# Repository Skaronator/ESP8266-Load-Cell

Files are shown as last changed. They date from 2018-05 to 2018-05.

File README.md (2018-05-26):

# ESP8266 Load Cell
A MQTT client to read out the result of HX711 and send it to a MQTT Broker.

#### This is a (somewhat) fork of [newAM/LoadCellOccupany](https://github.com/newAM/LoadCellOccupany/). Be sure to check his repository out!

## Hardware

This is the exact Hardware I'm using. It cost around 5-10€ on AliExpress.
- ESP8266 - [WeMos D1 mini Pro](https://wiki.wemos.cc/products:d1:d1_mini_pro)
- ADC - HX711
- Load Cell - Search for "50kg load cell hx711" on AliExpress. It'll have a HX711 included.
- 3D printed case for the load cell.

## Software

You need some libarys to compile this Arduino Sketch.
- [esp8266/Arduino](https://github.com/esp8266/Arduino#installing-with-boards-manager) - Install via Arduino IDE
- [async-mqtt-client](https://github.com/marvinroger/async-mqtt-client) - [ZIP Download](https://codeload.github.com/marvinroger/async-mqtt-client/zip/master)
- [ESPAsyncTCP](https://github.com/me-no-dev/ESPAsyncTCP) - [ZIP Download](https://codeload.github.com/me-no-dev/ESPAsyncTCP/zip/master)
- [HX711](https://github.com/bogde/HX711) - [ZIP Download](https://codeload.github.com/bogde/HX711/zip/master)

Please [open a Issue](https://github.com/Skaronator/ESP8266-Load-Cell/issues) if you have trouble to compile.

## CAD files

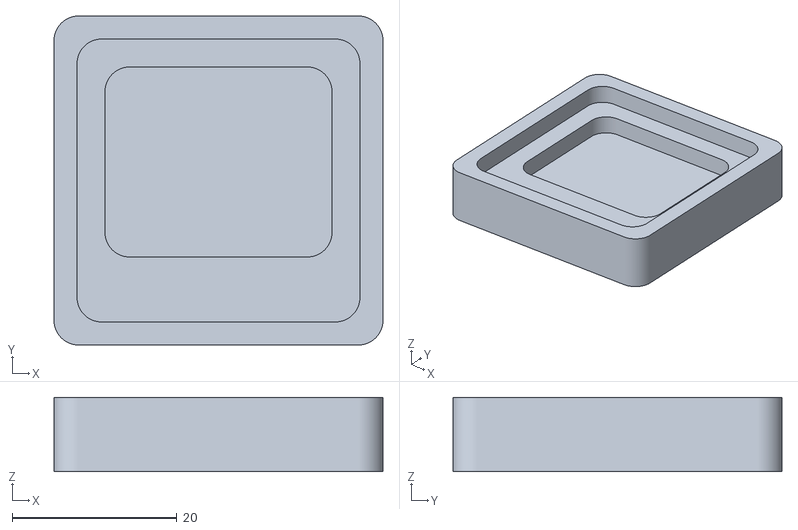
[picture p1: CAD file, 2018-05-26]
3D-Print/LoadCell_Holder_modified.stl
40.0 x 40.0 x 9.00

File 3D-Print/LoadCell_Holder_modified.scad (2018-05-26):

// render settings
fn  = 100;     // sides to render on cylinder
cut = 0.001;   // exact cutouts do not render

// Makes a cube shape with rounded corners in the z-direction
// dim[x,y,z] - vector containing outer dimensions of the cube
// rad        - radius of the rounded corners 
module RoundCorners(dim, rad) {
    // create adjusted dimensions for corners
    adjDim = [dim[0] - rad * 2, dim[1] - rad * 2, dim[2]];

    hull() {
        // place cylinders at each corner
        for (x = [1, -1])
            for (y = [1, -1])
                translate([x * adjDim[0] / 2,   y * adjDim[1] / 2, 0])
                    cylinder(h = adjDim[2], r = rad, center = true, $fn = fn);

        // place main body
        cube(adjDim, center = true);
    }
}

// clearances
clear = 0.2;    // clearance from load cell to wall

// load cell measured dimensions
loadCellX = 34;  // length and width of load cell
loadBaseX = 3;   // width of load cell base
loadBaseB = 7.5; // width of load cell base at the strain gauge

// wall thickness
wall = 3;        // wall thickness

roundR = 3;      // radius of rounded corners

// derived dimensions
base    = [loadCellX + wall * 2, loadCellX + wall * 2, wall];
baseCut = [loadCellX - (loadBaseX + clear) * 2, 
           loadCellX - loadBaseX - loadBaseB - clear * 2, 
           wall + cut];
wallCut = [loadCellX + clear * 2, 
           loadCellX + clear * 2, 
           base[2] + cut];
           
flatBase = [loadCellX + wall * 2, loadCellX + wall * 2, wall];

union() {
    // base with cutout for load cell to deflect
    difference() {
        RoundCorners(base, roundR);
        translate([0, (loadBaseB - loadBaseX) / 2, 0])
            RoundCorners(baseCut, roundR);
    }
    
    difference() {
        translate([0, 0, wall * -1])
            RoundCorners(flatBase, roundR);
    }

    // walls to hold load cell
    difference() {
        translate([0, 0, wall])
            RoundCorners(base, roundR);
        translate([0, 0, wall])
            RoundCorners(wallCut, roundR);
    }
}

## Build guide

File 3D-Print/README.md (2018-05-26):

This is a modified version of [**@newAM**](https://github.com/newAM) load cell holder. It has a solid base (3mm) to mount it better with double sided tape.

Original Version: https://github.com/newAM/LoadCellOccupany/tree/master/LoadCell_Holder

Software used: [OpenSCAD](http://www.openscad.org/)

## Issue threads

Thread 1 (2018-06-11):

Number of load cells

danpowell88, 2018-06-11:
Are you using a single load cell or multiple?

Skaronator, 2018-06-24:
Sorry for the late response! I didn't got a E-Mail or missed it...

I'm using 4 loadcells on a single HX711. Here is the wiring diagram:

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

Closed 2018-06-24.

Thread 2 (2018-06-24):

Reset oldResult variable on MQTT Disconnect

Skaronator, 2018-06-24:
When the MQTT server goes offline and comes back it should re-send the current value.

Skaronator, 2018-09-10:
It should also send the value every x min even if it didn't changed to show that the device is still alive.

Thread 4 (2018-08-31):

Connection Photos

bachoo786, 2018-08-31:
Hello

Can you please show the connection of the load cells to the load cell sensor as well as to the Wemos?

Thank you.

Skaronator, 2018-08-31:
Hey,

did you saw the image in #1? The HX711 is via Pin D3 and D4:

https://github.com/Skaronator/ESP8266-Load-Cell/blob/ea1dd6d372639417d1c046c552d9748194dad7fe/code/config.h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

Here is the best image I could get without unpluging it :p

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

Skaronator, 2018-09-10:
If you have more questions, feel free to comment below.

bachoo786, 2018-10-01:
hey @Skaronator didnt realize that you had replied.

I tried to upload the code to my esp8266 board but it gives an error saying pin D3 and D4 have not been defined in config.h ? I thought they were already pre-defined?

Thanks.

bachoo786, 2018-11-18:
Hi thanks for the reply
I mounted the load sensors on my bed 4 of them but the weight is not distributed on the mattress as the sensor does not detect the weight until pressured is applied on it i.e. on the side of the bed.

Do you have any idea what could be wrong?

Closed 2018-09-10.

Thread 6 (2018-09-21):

Getting boot loop errors

hammondses, 2018-09-21:
Hi there,

I'm attempting to get my Wemos D1 Mini Pro working with your bed sensor scripts, however after flashing both files I'm getting reboot errors.

I modified config.h to suit my config, should I try it with yours?

I'm really new to the whole ESP8266 thing so please be gentle :)

I have wired it all correctly (I think) SCL -> SCK, SDA -> DT, 5v -> VCC & GND -> GND from ESP to HX711. I followed the diagram provided for the weight sensors to be wired to eachother and back to the HX711.

In the Serial Monitor I get total garbage at 9600 baud, but at 115200 I get this:

```
ets Jan  8 2013,rst cause:2, boot mode:(3,7)

load 0x4010f000, len 1384, room 16
tail 8
chksum 0x2d
csum 0x2d
vbb28d4a3
~ld
```

Any help would be greatly appreciated!

hammondses, 2018-09-21:
Update: Fixed my bootloop issues, issue was I needed to change the pins in the config, so now it boots but my monitor is full of absolute garbage no matter the baud I use :(

Skaronator, 2018-09-21:
I'm actually not sure why the output is sometimes just garbage.

Did you install the Wemos Board Stuff? https://www.instructables.com/id/Programming-the-WeMos-Using-Arduino-SoftwareIDE/

hammondses, 2018-09-21:
I think it's because it's a knock off from AliExpress, the WiFi test module seems to do nothing which doesn't look like a good sign from what I've been reading

Skaronator, 2018-09-21:
Could you make a picture of it and maybe link the AliExpress product?

hammondses, 2018-09-21:
https://s.click.aliexpress.com/e/b8QSpZQY

I'm not at home right now but I'll take a picture of it tomorrow when I'm home

Skaronator, 2018-09-21:
Weird thats a LOLIN and not a Wemos. Mine looks completly different but just checked the Wemos page and it looks like they have a new version? https://wiki.wemos.cc/products:d1:d1_mini_pro

Mine looks like this: (Notice the ceramic antenna)

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

hammondses, 2018-09-21:
I think the easiest thing for me to do is probably buy the same one you have, this is it? - https://www.trademe.co.nz/1773192104

Skaronator, 2018-09-21:
Yes I think so but $14 is too expensive for that. This is what I've ordered earlier this year: https://www.aliexpress.com/item/WEMOS-D1-Mini-Pro-V1-0-16M-Bytes-External-Antenna-Connector-NodeMCU-ESP8266-ESP8266F-CP2104-WIFI/32861321679.html

(Just noticed that 1.0 not 1.1 but shouldn't matter)

Skaronator, 2018-09-21:
Bascially it should be possible to run this on the v2 version but I don't have the hardware to validate this. Maybe I'll order some but it'll take almost a month until they are here.

hammondses, 2018-09-21:
Ah, it's in NZD. The AliExpress link you gave is $11.77 so not too bad for it being local. I'll order one and let you know how I get on :)

Skaronator, 2018-09-21:
Oh it's local? Didn't know that. The AliExpress link is $5 for me.

hammondses, 2018-09-21:
Yeah, I did mean Inc shipping :)

I guess the issue too is that it's pretty difficult to find someone to test it who happens to have load sensors and the v2 hardware

hammondses, 2018-09-23:
I'm now getting this error after fixing the pinouts in the code:

`16:52:26.210 ->  ets Jan  8 2013,rst cause:2, boot mode:(3,6)
16:52:26.210 ->
16:52:26.210 -> load 0x4010f000, len 1384, room 16
16:52:26.210 -> tail 8
16:52:26.210 -> chksum 0x2d
16:52:26.210 -> csum 0x2d
16:52:26.255 -> vbb28d4a3
16:52:26.255 -> ~ld
`

hammondses, 2018-09-23:
I decided to test the esp with a whole range of test sketches and it seems like all of the onboard functions are working and the HX711 calibration sketch gives me readouts of the load sensors.

After a bit of googling it seems it's quite a common error I'm getting when trying to use the hx711 and an esp8266, apparently putting in a yeild somewhere can fix it?

See here - https://github.com/bogde/HX711/issues/67

bachoo786, 2018-10-04:
@hammondses did you upload the code before connecting hx711 and the load cells?  Because I am uploading the code before attaching anything onto my esp8266 and I get errors as described in your first post.

Please help.

hammondses, 2018-10-04:
I uploaded the code after connecting everything, which hardware revision are you using?

bachoo786, 2018-10-04:
Sorry what do you mean by hard revision ?

hammondses, 2018-10-04:
Oh sorry I meant which esp do you have? I had the new version of the d1 mini pro which didn't seem to like the code so I'm waiting for the same revision to arrive which the creator has :)

bachoo786, 2018-10-04:
I have the old version of d1 mini  and have the nodemcu none of them work I get the same error as described earlier.

hammondses, 2018-10-07:
Hmm how odd, @Skaronator any suggestions?

Skaronator, 2018-10-07:
Sorry, can't really help you since I'm relatively new to the whole Arduino stuff.

hammondses, 2018-10-14:
@bachoo786 Which error are you seeing? If its the absolute garbage in the output monitor I fixed it on mine, I had to run a script to set the default baud rate of the ESP8266 to 9600 and did an AT+IPR=9600 command, then uploaded the sketch (I can't remember if it was sketch only or sketch+wifi) and it seems to have fixed it.

I gave up trying to get my version 2 board working, but the one that you have and the OP has I got working after setting the default baud rate of the board lower.

Let me know how you get on!

hammondses, 2018-10-17:
@Skaronator what does your history graph for the sensor look like? For some reason i'm experiencing huge weight fluctuations randomly in the middle of the night or during the day for a few moments then back to normal. See attached picture

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

amotl, 2019-02-19:
Hi there, just wanted to let you know we are working on https://github.com/bogde/HX711/pull/123, which you might want to give a try. It is an attempt to remedy some of the issues of this library, especially when it came to ESP8266 and ESP32 support.

sagartec, 2019-10-19:
@hammondses did you solve the reset problem. I am also facing the same issue now.

hammondses, 2019-10-19:
Yeah I ended up changing to the exact same board as the original poster was using, also noticed some boards don't like having the letter in the pinout, ie D3 D2 I changed to 3 and 2 which resolved my issues with other projects.

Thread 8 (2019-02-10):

Crash every now & then

riemers, 2019-02-10:
I have all running, i added a scale set option since when i restart i would not be in bed ;)

Problem is it sometimes just 'dies'. When that happens it restarts dumping errors on the screen before restarting. Somtimes it works for a long time and sometimes it just goes into the reboot phase.

Is there anything i can do to improve this/debug?

Other then that, the instructions where just fine. Only thing i didn't know was that you need the molds otherwise it doesn't bend correctly. (i was just pressing it for testing, gives weird values)

amotl, 2019-02-19:
Hi there, this might be a duplicate of #6 already. Just wanted to let you know we are working on https://github.com/bogde/HX711/pull/123, which you might want to give a try. It is an attempt to remedy some of the issues of the Arduino HX711 library, especially when it came to ESP8266 and ESP32 support.

riemers, 2019-02-19:
i have a wemos mini i believe, but if this would reduce the 'crashes' that would certainly help. Time is shorthanded but if i do i'll test it out.

amotl, 2019-02-20:
@bogde [confirmed](https://github.com/bogde/HX711/pull/123#issuecomment-465038328) that the revamped code works out of the box with a WeMos D1 mini (ESP8266) already. There are chances it might be actually behave better as the library gained minor but important improvements through suggestions from the community.

So, if you like give it a try. However I can't promise the overall system stability will actually be better using the improved HX711 code as there might be other things involved. Good luck!

riemers, 2019-03-04:
@amotl i've tested it out, it does seem a lot more stable now. Only weird thing is that i get random values sometimes.

14:29:34.216 -> Pushing new result:    0
14:51:40.903 -> Pushing new result:  -43
14:51:41.417 -> Pushing new result:    0
15:01:47.977 -> Pushing new result:   -1
15:01:48.566 -> Pushing new result:    0
15:06:54.438 -> Pushing new result:   -1
15:06:54.954 -> Pushing new result:    0
23:13:29.948 -> Pushing new result:   -1
23:13:30.427 -> Pushing new result:   22
23:13:30.939 -> Pushing new result:    0
20:25:56.308 -> Pushing new result:   20
20:25:56.792 -> Pushing new result:    0

When it happens its pretty quick to drop back to 0, have no load on it. But its a bit weird to be so spikey (this is in kg)

amotl, 2019-03-04:
Dear @riemers,

> i've tested it out, it does seem a lot more stable now

Thanks for testing, sounds good.

> Only weird thing is that i get random values sometimes.

The readings as displayed are obviously weird. While we did our best to incorporate all the relevant changes into https://github.com/bogde/HX711/pull/123 where some of them also account for reading the data from the hardware using faster chips, there might still be issues with the ESP8266 we dearly would like to find out about.

### Research
When searching for other issues about random readings over at https://github.com/bogde/HX711, I've found two issues which might be relevant:

- https://github.com/bogde/HX711/issues/28#issuecomment-191370341
  > I actually stopped using the HX711 because at higher read rates (40Hz) it would seem to randomly give bad data. I have a suspicion this is actually due to the internal buffer getting updated with a new conversion while you're still clocking out the previous conversion data. I also needed 100Hz conversion, so I moved to ADS1232 with an external clock.
- https://github.com/bogde/HX711/issues/47

### Thoughts
So, while the current code should account for properly slowing down the reading from the hardware appropriately (https://github.com/bogde/HX711/blob/0.7.2/src/HX711.cpp#L36-L62), let's check this twice: Can we humbly ask you to run your sketch either with reduced clock speed or by adjusting the value used within the calls to `delayMicroseconds(1);` there?

### Advise
We would also recommend to open a corresponding issue over at https://github.com/bogde/HX711/issues/new to get more eyeballs on that.

Thanks already for your efforts.

With kind regards,
Andreas.

riemers, 2019-03-05:
I'll see what i can do, i still have the "test" setup on my desk. Just need some time :)

riemers, 2019-03-05:
Also noticed some crashes again:

```
14:36:50.017 -> Pushing new result:    0
14:36:57.611 -> [WiFi] Disconnected from Wi-Fi!
14:36:58.568 -> Pushing new result:    3
14:36:59.050 -> Pushing new result:    0
14:36:59.627 -> [WiFi] Connecting to n176...
14:36:59.627 ->
14:36:59.627 -> Exception (9):
14:36:59.662 -> epc1=0x40105068 epc2=0x00000000 epc3=0x00000000 excvaddr=0x00000003 depc=0x00000000
14:36:59.766 ->
14:36:59.766 -> >>>stack>>>
14:36:59.766 ->
14:36:59.766 -> ctx: sys
14:36:59.766 -> sp: 3fffed10 end: 3fffffb0 offset: 01a0
14:36:59.835 -> 3fffeeb0:  40105294 21f39217 3ffee968 00000000
```

```
15:30:44.045 -> Pushing new result:    0
16:31:21.412 -> [WiFi] Disconnected from Wi-Fi!
16:31:23.395 -> [WiFi] Connecting to n176...
16:31:23.395 ->
16:31:23.395 -> Exception (9):
16:31:23.429 -> epc1=0x40105068 epc2=0x00000000 epc3=0x00000000 excvaddr=0x00000003 depc=0x00000000
16:31:23.531 ->
16:31:23.531 -> >>>stack>>>
16:31:23.531 ->
16:31:23.531 -> ctx: sys
16:31:23.531 -> sp: 3fffed10 end: 3fffffb0 offset: 01a0
16:31:23.600 -> 3fffeeb0:  40105294 1f4dd11d 3ffee968 00000000
```

Looking at this, the wifi is disconnecting for some reason, but when it reconnects it crashes.

Later on:

```
16:31:32.688 -> [WiFi] Connecting to n176...
16:31:33.204 -> Pushing new result:    0
16:31:33.887 -> [WiFi] Disconnected from Wi-Fi!
16:31:34.644 -> [WiFi] Connected, IP address: 192.168.1.23
16:31:34.678 -> [MQTT] Connecting to MQTT...
16:31:49.273 -> Pushing new result:   -0
16:31:51.290 -> Pushing new result:    0
```

Seems that if it wants to push a new value while it was disconnect or just about might make it crash. (assuming not related to hx711(

Your saying to delay, but do you mean a delay in my void loop? Since it already has a 100ms delay.

riemers, 2019-03-07:
Is it normal that it crashes totally too? I changed the sample rates:

#define SAMPLE_PERIOD 100    // sample period in ms
#define NUM_SAMPLES   10      // number of samples - max 255 - published mqtt update every NUM_SAMPLES * SAMPLE_PERIOD = ms

```
22:43:11.645 -> [WiFi] Disconnected from Wi-Fi!
22:43:13.130 -> Pushing new result:  0.0
22:43:14.520 -> [WiFi] Disconnected from Wi-Fi!
22:43:18.154 -> Pushing new result: -0.0
22:43:19.158 -> Pushing new result:  0.0
22:43:19.503 -> [WiFi] Connecting to n176...
22:43:26.987 -> H⸮)2
```

Also notice no longer a blue light anymore and no reaction anymore. But with 100/10 it was not better. With 200/5 it was only a few kg minus sometimes. I'll try 300/3 now :)

amotl, 2019-03-07:
Dear @riemers,

sorry that it doesn't work for you. Would there be any chance you could try this with a more recent firmware version? I believe the ESP8266 had some issue with older firmwares which have been similar to what you are reporting. Also, I haven't investigated [LoadCell.ino](https://github.com/Skaronator/ESP8266-Load-Cell/blob/master/code/LoadCell.ino) in detail yet, where things might go wrong too.

With kind regards,
Andreas.

riemers, 2019-03-09:
@amotl i'am pretty new to the boards, i only know i can flash a sketch from arduino ide or use the espeasy which also seems to support hx711 in the test environment. Have a wemos d1 mini and have yet to find a newer 'firmware'. I tried espeasy too, but this is just an easy gui thing for people, not really my thing when it comes to keeping it clean and simple ;) any pointers/hints and i'll check it out.

amotl, 2019-03-09:
Thanks for the insight, @riemers. Then, I would recommend to start small again by testing with one of the canonical examples provided with the HX711 library.

Why not start over with the most basic one ([HX711_basic_example.ino](https://github.com/bogde/HX711/blob/master/examples/HX711_basic_example/HX711_basic_example.ino)) again, in order to check that this (hopefully!) **does not** crash your machine.

riemers, 2019-03-09:
Ah yes, start from basic is a good idea too. I have it hooked up to the com anyways. I can just let it sit and see if its stable and then expand if it runs good for a few days etc etc. I'll keep you posted (then you know if it has any relationship with hx711)

riemers, 2019-03-09:
20:50:15.387 -> HX711 reading: -150552
20:50:16.380 -> HX711 not found.
20:50:17.403 -> HX711 reading: -150494

That normal now and then?

amotl, 2019-03-09:
Interesting, thanks for letting us know. I really can't tell anything about effects like that. Obviously all of us expect stable readings and I didn't hear about corresponding reports either.

As far as I learned, many things can contribute to things going wrong when reading the HX711.

"not found" would actually be a bit misleading here. It should really be called "not available" or "unable to read" or such.

Is the rate of valid readings acceptable for you? I mean, **if** they're actually valid then.

riemers, 2019-03-09:
Well you have to tare it, but other then that the value is now around -151000 and its doesn't go higher/lower then +- 250 side ways. (From what i gather, thats pretty descent)

The **not found** has happened now 8 times since 20:37 till now. I would call that "acceptable" since we read it out so many times anyways.

amotl, 2019-03-09:
Hi @riemers,

when taking a reading each second, eight faulty readings during more than two hours also seems acceptable for this ensemble of hardware and software, right? We are not conducting measurements for ATLAS here in the end.

With kind regards,
Andreas.

riemers, 2019-03-09:
Indeed, i'll leave it spitting out values for a couple of days. I normally had about 1 or 2 days tops before it went for a coffee break.

riemers, 2019-03-14:
Did some more testing, found out that the example was doing just fine. Only difference was that it sits at 115200. Had mine at 9600. Weirdly enough my original sketch is running now fine for 3 days without a crash when i changed it to 115200. Might be luck? Dunno but i'll keep it running for the weekend too and if it does then that was the culprit (although i believe it should not matter at all right?)

riemers, 2019-03-21:
@amotl well its been running now for more then a week and has not crashed anymore. Is it really that silly that the speed @ 115200 makes it not crash? Either way, i'am happy its running ok now :)

bogde, 2019-03-22:
@riemers it does make some sense though. since serial communication is now faster, it's less likely for that to interfere with anything else. glad it works for you now. cheers!

amotl, 2019-03-22:
Thanks for letting us know, have a good weekend and also cheers!

riemers, 2019-03-22:
We can close this, but a note somewhere might be good althought the example was with a higher rate. That was the only thing different when testing.

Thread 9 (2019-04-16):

Some step by step help for a noob

jjanderson, 2019-04-16:
Hello,

I am sorry to ask, but do you have some step by step instructions? I have never done a project like this, but I am desperate to try. I have just ordered all the components you listed.

Sorry for the stupid question, but will I also need an adruino board in addition to the hardware you listed?

Thanks for any help you are able to provide. My goal is to add this bed occupancy sensor to our toddlers bed and then plug into Home Assistant... possibly using the ESPHome component...

Thanks again for any help you can give me

aaamoeder, 2019-05-16:
I'd love this too.. no idea how to wire this up .. some pictures, and steps would be great !

jjanderson, 2019-05-16:
I have most of the kit now, just wanted to add this piece to the recommended hardware: [https://www.sparkfun.com/products/13878](url)

As the load cells have a rather short wire, I will need to extend the wires as well which will add further complication. (I want to use this on a baby cot)

Anyway, I would be happy to write this up as soon as I get it right…

Ulrar, 2019-10-15:
Hey,

Did you manage to get this working in the end ?
I would also be interested in details on how this all fits together.

qHack, 2020-01-04:
Anyone make progress here? I’m a software engineer by trade, need some pointers in the hardware parts.

jjanderson, 2020-02-27:
I am useless with a soldering iron, but hopefully will have it all hooked up by the weekend....

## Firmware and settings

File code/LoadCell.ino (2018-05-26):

// Required Libarys:
// async-mqtt-client:  https://codeload.github.com/marvinroger/async-mqtt-client/zip/master
// ESPAsyncTCP:        https://codeload.github.com/me-no-dev/ESPAsyncTCP/zip/master
// HX711:              https://codeload.github.com/bogde/HX711/zip/master

#include <ESP8266WiFi.h>
#include <EEPROM.h>
#include <Ticker.h>
#include <AsyncMqttClient.h>
#include <HX711.h>
#include <ArduinoOTA.h>
#include "config.h"


HX711 scale(PIN_DOUT, PIN_CLK);

AsyncMqttClient mqttClient;
Ticker mqttReconnectTimer;

WiFiEventHandler wifiConnectHandler;
WiFiEventHandler wifiDisconnectHandler;
Ticker wifiReconnectTimer;

bool firstRun = true;
unsigned char samples;
int sum, average, offset;
char oldResult[10];

void eeWriteInt(int pos, int val) {
    byte* p = (byte*) &val;
    EEPROM.write(pos, *p);
    EEPROM.write(pos + 1, *(p + 1));
    EEPROM.write(pos + 2, *(p + 2));
    EEPROM.write(pos + 3, *(p + 3));
    EEPROM.commit();
}

int eeGetInt(int pos) {
  int val;
  byte* p = (byte*) &val;
  *p        = EEPROM.read(pos);
  *(p + 1)  = EEPROM.read(pos + 1);
  *(p + 2)  = EEPROM.read(pos + 2);
  *(p + 3)  = EEPROM.read(pos + 3);
  return val;
}


void connectToWifi() {
  Serial.printf("[WiFi] Connecting to %s...\n", WIFI_SSID);

  WiFi.hostname(WIFI_CLIENT_ID);
  WiFi.mode(WIFI_STA);
  if (WIFI_STATIC_IP != 0) {
    WiFi.config(WIFI_CLIENT_IP, WIFI_GATEWAY_IP, WIFI_SUBNET_IP, WIFI_DNS_IP);
  }

  delay(100);

  WiFi.begin(WIFI_SSID, WIFI_PASSWORD);
}

void onWifiConnect(const WiFiEventStationModeGotIP& event) {
  Serial.print("[WiFi] Connected, IP address: ");
  Serial.println(WiFi.localIP());
  wifiReconnectTimer.detach();
  connectToMqtt();
}

void onWifiDisconnect(const WiFiEventStationModeDisconnected& event) {
  Serial.println("[WiFi] Disconnected from Wi-Fi!");
  mqttReconnectTimer.detach(); // ensure we don't reconnect to MQTT while reconnecting to Wi-Fi
  wifiReconnectTimer.once(WIFI_RECONNECT_TIME, connectToWifi);
}

void connectToMqtt() {
  Serial.println("[MQTT] Connecting to MQTT...");
  mqttClient.connect();
}

void onMqttConnect(bool sessionPresent) {
  Serial.println("[MQTT] Connected to MQTT!");

  mqttReconnectTimer.detach();

  Serial.print("Session present: ");
  Serial.println(sessionPresent);
  uint16_t packetIdSub = mqttClient.subscribe(MQTT_TOPIC_TARE, MQTT_TOPIC_TARE_QoS);
  Serial.print("Subscribing to ");
  Serial.println(MQTT_TOPIC_TARE);
}

void onMqttDisconnect(AsyncMqttClientDisconnectReason reason) {
  Serial.println("[MQTT] Disconnected from MQTT!");

  if (WiFi.isConnected()) {
    Serial.println("[MQTT] Trying to reconnect...");
    mqttReconnectTimer.once(MQTT_RECONNECT_TIME, connectToMqtt);
  }
}

void onMqttMessage(char* topic, char* payload, AsyncMqttClientMessageProperties properties, size_t len, size_t index, size_t total) {
  if (!strcmp(topic, MQTT_TOPIC_TARE)) {
    Serial.print("Zeroing: ");
    Serial.println(average / (float) 100);
    offset = average;
    if (SAVE_TARE != 0) {
      Serial.print("Saving to EEPROM...");
      eeWriteInt(EEPROM_ADDRESS, offset);
    }
  }
}

void setup() {
  Serial.begin(9600);
  EEPROM.begin(512);
  Serial.println("Startup!");

  wifiConnectHandler = WiFi.onStationModeGotIP(onWifiConnect);
  wifiDisconnectHandler = WiFi.onStationModeDisconnected(onWifiDisconnect);

  mqttClient.onConnect(onMqttConnect);
  mqttClient.onDisconnect(onMqttDisconnect);
  mqttClient.onMessage(onMqttMessage);
  mqttClient.setServer(MQTT_HOST, MQTT_PORT);

  if (MQTT_USER != "") {
    mqttClient.setCredentials(MQTT_USER, MQTT_PASS);
  }

  if (SAVE_TARE == 1) {
    offset = eeGetInt(EEPROM_ADDRESS);

    Serial.print("Loading offset from EEPROM: ");
    Serial.println(offset / (float) 100);
  }

  scale.set_scale(CALIBRATION);

  if (OTA_PATCH == 1) {
    ArduinoOTA.onStart([]() {
      String type;
      if (ArduinoOTA.getCommand() == U_FLASH) {
        type = "sketch";
      } else { // U_SPIFFS
        type = "filesystem";
      }

      // NOTE: if updating SPIFFS this would be the place to unmount SPIFFS using SPIFFS.end()
      Serial.println("Start updating " + type);
    });
    ArduinoOTA.onEnd([]() {
      Serial.println("\nEnd");
    });
    ArduinoOTA.onProgress([](unsigned int progress, unsigned int total) {
      Serial.printf("Progress: %u%%\r", (progress / (total / 100)));
    });
    ArduinoOTA.onError([](ota_error_t error) {
      Serial.printf("Error[%u]: ", error);
      if (error == OTA_AUTH_ERROR) {
        Serial.println("Auth Failed");
      } else if (error == OTA_BEGIN_ERROR) {
        Serial.println("Begin Failed");
      } else if (error == OTA_CONNECT_ERROR) {
        Serial.println("Connect Failed");
      } else if (error == OTA_RECEIVE_ERROR) {
        Serial.println("Receive Failed");
      } else if (error == OTA_END_ERROR) {
        Serial.println("End Failed");
      }
    });

    ArduinoOTA.setHostname(WIFI_CLIENT_ID);
    ArduinoOTA.setPassword(OTA_PASS);


    ArduinoOTA.begin();
  }

  connectToWifi();
}

void loop() {
  if (WiFi.isConnected() && (OTA_PATCH != 0)) {
    ArduinoOTA.handle();
  }

  sum += scale.get_units() * 100;
  samples++;

  if (samples >= NUM_SAMPLES) {
    if (firstRun) {
      firstRun = false;
      if (SAVE_TARE == 0) {
        average = offset;
        return;
      }
    }

    char result[10];
    average = sum / samples;
    dtostrf(((average-offset) / (float) 100), 5, RESOLUTION, result);

    if (mqttClient.connected() && strcmp(result, oldResult)) {
      mqttClient.publish(MQTT_TOPIC_LOAD, MQTT_TOPIC_LOAD_QoS, true, result);
      Serial.print("Pushing new result:");
      Serial.println(result);
    }

    strncpy(oldResult, result, 10);
    samples = 0;
    sum = 0;
  }

  delay(SAMPLE_PERIOD);
}

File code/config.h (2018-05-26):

// Required Libarys:
// async-mqtt-client:  https://codeload.github.com/marvinroger/async-mqtt-client/zip/master
// ESPAsyncTCP:        https://codeload.github.com/me-no-dev/ESPAsyncTCP/zip/master
// HX711:              https://codeload.github.com/bogde/HX711/zip/master

// MQTT Broker Config
#define MQTT_HOST IPAddress(192, 168, 178, 5)
#define MQTT_PORT 1883
#define MQTT_USER "homeassistant"
#define MQTT_PASS "your_passwd"
#define MQTT_RECONNECT_TIME 2 // in seconds

// MQTT Client Config
#define MQTT_CLIENT_ID "/room/<room_name>/bed"
#define MQTT_TOPIC_LOAD MQTT_CLIENT_ID "/load"
#define MQTT_TOPIC_LOAD_QoS 0 // Keep 0 if you don't know what it is doing
#define MQTT_TOPIC_TARE MQTT_CLIENT_ID "/tare"
#define MQTT_TOPIC_TARE_QoS 0 // Keep 0 if you don't know what it is doing

// WiFi Config
#define WIFI_SSID "YourWiFi_SSID"
#define WIFI_PASSWORD "YourWiFi_PW"
#define WIFI_CLIENT_ID "BED-210"
#define WIFI_RECONNECT_TIME 2 // in seconds

// Wifi optional static ip (leave client ip empty to disable)
#define WIFI_STATIC_IP    0 // set to 1 to enable static ip
#define WIFI_CLIENT_IP    IPAddress(192, 168, 178, 210)
#define WIFI_GATEWAY_IP   IPAddress(192, 168, 178, 1)
#define WIFI_SUBNET_IP    IPAddress(255, 255, 255, 0)
#define WIFI_DNS_IP       IPAddress(192, 168, 178, 4)

#define OTA_PATCH 1 // Set to 0 if you don't want to update your code over-the-air
#define OTA_PASS "set_ota_password"

// HX711 Config
#define PIN_DOUT D3
#define PIN_CLK  D4

// Get Data:
#define CALIBRATION   -11000 // ADC bits to Kg conversion factor | modify this value if your reading are way off. Different cable length result in different values.
#define SAMPLE_PERIOD 100    // sample period in ms
#define NUM_SAMPLES   5      // number of samples - max 255 - published mqtt update every NUM_SAMPLES * SAMPLE_PERIOD = ms

// Send Data:
#define RESOLUTION    1      // number of characters after the decimal - 0, 1 or 2 is supported.

// Save the Tare to EEPROM.
// Set 0 to disable. It'll tare once the device has started.
// Set 1 to save the tare offset to EEPROM - it'll be saved while restarting/power off
#define SAVE_TARE      1
#define EEPROM_ADDRESS 0 // You can change this adress after a while to reduce the wear on the EEPROM
